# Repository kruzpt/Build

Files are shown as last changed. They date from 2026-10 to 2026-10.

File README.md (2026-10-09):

# Clínica Essencial — placa QR e NFC

Projeto de uma placa de balcão para impressão 3D e edição no Autodesk Fusion.

## Ficheiros

- **[Base Premium — download separado, encaixe original](downloads/essencial-base-premium.zip?raw=true)**
- [Base Premium — código Fusion](fusion/EssencialBasePremium/EssencialBasePremium.py)
- [Base Premium — medidas e instruções](fusion/EssencialBasePremium/README.md)
- [Base Premium — esquema das medidas](designs/essencial-base-premium-medidas.png)
- **[A1 + avaliações Google — download atual](downloads/essencial-fusion-a1-avaliacoes.zip?raw=true)**
- [A1 + avaliações Google — código Fusion](fusion/EssencialA1Reviews/EssencialA1Reviews.py)
- [A1 + avaliações Google — esquema atualizado](designs/essencial-a1-avaliacoes-esquema.png)
- [Instruções e endereços para programar NFC](fusion/EssencialA1Reviews/README.md)
- **[Bambu A1 — download (link Google ainda provisório)](downloads/essencial-fusion-a1.zip?raw=true)**
- [Bambu A1 — código Fusion](fusion/EssencialA1/EssencialA1.py)
- [Bambu A1 — esquema com dimensões completas](designs/essencial-a1-esquema.png)
- [Bambu A1 — instruções e pendência do link de avaliações](fusion/EssencialA1/README.md)
- **[V4 — download com QR de 64 mm](downloads/essencial-fusion-v4-qr64.zip?raw=true)**
- [V4 — código Fusion](fusion/EssencialV4/EssencialV4.py)
- [V4 — esquema atualizado](designs/essencial-v4-qr64-esquema.png)
- [V4 — dimensões e impressão](fusion/EssencialV4/README.md)
- **[V3 Fast — download da versão otimizada](downloads/essencial-fusion-v3-fast.zip?raw=true)**
- [V3 Fast — código e indicação de progresso](fusion/EssencialV3Fast/EssencialV3Fast.py)
- [V3 Fast — instruções](fusion/EssencialV3Fast/README.md)
- **[V3 — dois QR, símbolos e etiquetas NFC encapsuladas](fusion/EssencialV3/EssencialV3.py)**
- [Download do pacote Fusion V3](downloads/essencial-fusion-v3.zip?raw=true)
- [V3 — esquema frontal](designs/essencial-v3-esquema.png)
- [V3 — instruções de pausa e montagem](fusion/EssencialV3/README.md)
- [Placa Fusion com QR Instagram integrado](fusion/EssencialV2Instagram/EssencialV2Instagram.py)
- [Download: Fusion + STL QR + imagem](downloads/essencial-fusion-instagram.zip?raw=true)
- [STL: pastilha QR independente](downloads/instagram-qr-51mm.stl?raw=true)
- [QR Instagram — imagem](designs/instagram-qr.png)
- [Instruções de impressão e contraste do QR](fusion/README-Instagram.md)
- [Script V2 — duas peças e nova coluna](fusion/EssencialV2/EssencialV2.py)
- [Instruções e medidas do encaixe V2](fusion/EssencialV2/README.md)
- [Download do pacote Fusion V2](downloads/essencial-fusion-v2.zip?raw=true)
- [Script Python para Fusion](fusion/EssencialDraft/EssencialDraft.py)
- [Como executar no Fusion](fusion/README.md)
- [Download do pacote Fusion](downloads/essencial-fusion-draft.zip?raw=true)
- [Desenho conceptual](designs/clinica-essencial-conceito-v1.png)
- [Download do desenho em ZIP](downloads/clinica-essencial-draft.zip?raw=true)

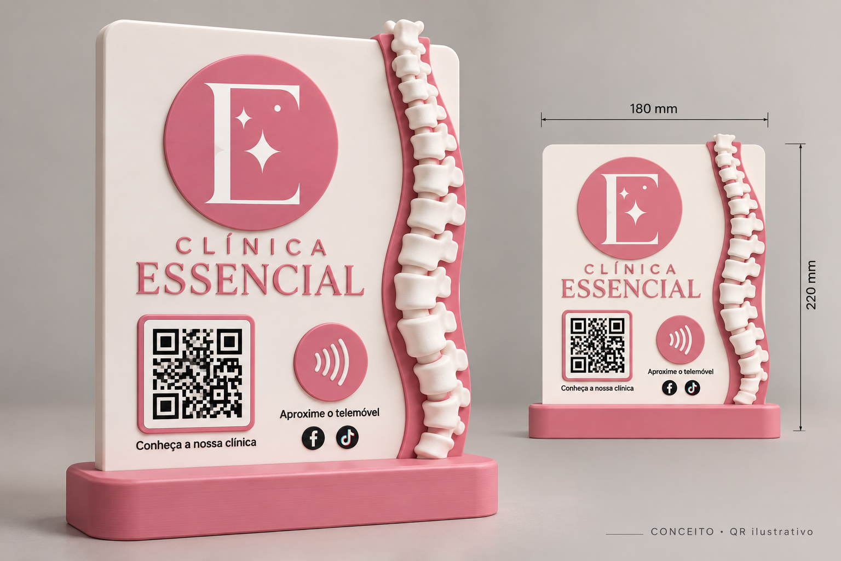
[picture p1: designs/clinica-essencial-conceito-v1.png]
Conceito inicial


O desenho conceptual mostra a primeira proposta. O script inclui uma alteração
posterior: logótipo a prolongar-se para fora do canto superior esquerdo, com a
mesma espessura da placa. Por isso, a imagem não representa exatamente o CAD.

## Estado do draft

A **Base Premium** substitui apenas a base: conserva 160 × 70 × 18 mm,
a ranhura útil 120,6 × 5,5 × 12,8 mm e a entrada alargada original.
Tem cantos R12, bordos superiores exteriores R2 e chanfro frontal de 8 mm,
sem alterar a zona de encaixe. O script é independente e cria um novo documento.

A versão atual **EssencialA1Reviews** mantém a peça completa com **208 × 242 mm**
e os QR de 64 mm. O Google abre o formulário de avaliação com o endereço que
o utilizador confirmou no navegador e no telemóvel. A matriz Google foi
regenerada com correção M para manter módulos de 1,422 mm; as cavidades NFC,
pausa Z=3,8 mm, encaixe e geração otimizada permanecem iguais. Use o mesmo
endereço de avaliações na etiqueta NFC inferior.

A versão anterior **Bambu A1** reorganiza o topo e reduz apenas o círculo do logótipo:
a placa completa, incluindo saliências e língua, fica com **208 × 242 mm**.
Com brim de 5 mm ocupa 218 × 252 mm. Mantém QR de 64 mm, etiquetas, pausa e
encaixe. **O QR Google ainda usa o link de partilha que abre pesquisa; o
endereço direto das avaliações está pendente e não foi substituído por um
endereço presumido.**

A **V4** aumenta os QR para 64 × 64 mm. A placa fica com 200 × 220 mm para
dar espaço aos símbolos, às zonas NFC e à coluna. Mantém a construção
otimizada dos QR, duas peças, as medidas da base/encaixe e a pausa após
Z=3,8 mm. Ambos os QR do esquema descodificam para os mesmos destinos.

A **V3 Fast** mantém a geometria da V3, mas gera os QR em duas extrusões
conjuntas em vez de 628 operações individuais. Inclui cálculo adiado dos
sketches e janela de progresso/cancelamento entre etapas. A igualdade dos
retângulos QR foi verificada; o tempo real no Fusion continua por confirmar.

A **V3** reorganiza a frente em duas linhas: Instagram/Google à esquerda,
respetivo QR no centro e símbolo contactless à direita. Não tem inscrições
“QR”/“NFC”. Mantém duas peças e inclui duas cavidades internas para etiquetas
NFC redondas de 25 mm, a inserir numa pausa após Z=3,8 mm. O E e as estrelas
foram redesenhados com curvas a partir da referência, sem barra central.
O logótipo é uma aproximação manual, não o vetor original. Consulte as
instruções antes de imprimir; ponte do teto, execução no Fusion e leitura
física ainda precisam de validação.

A variante **EssencialV2Instagram** inclui um QR funcional para
`https://www.instagram.com/clinicaessencial_setubal/`, em relevo e unido à
placa. O PNG e a projeção superior do STL foram descodificados para confirmar
o endereço; a impressão física e a execução da variante no Fusion continuam
pendentes. Use módulos pretos sobre fundo branco.

Placa de 180 × 220 × 5 mm, base separada, alojamento traseiro para etiqueta NFC
de 26 mm e zona reservada para QR. Na V2 sem Instagram, o QR não contém um endereço e a
etiqueta NFC tem de ser comprada e programada à parte. Letras são textos de
sketch, não sólidos para impressão. O logótipo é uma aproximação geométrica.

O utilizador confirmou que o script V1 executou no Fusion. A V2 substitui
os blocos por vértebras arredondadas com projeções curvas, tendo em conta um
bico de 0,4 mm. Cria duas peças, cada uma com um corpo sólido: placa e base.
A base tem uma ranhura de 5,5 mm para uma língua de 5 mm, com entrada alargada
e espaço no fundo. A V2 ainda precisa de execução no Fusion e teste físico
do encaixe; o draft não está validado para impressão final.

Os ficheiros entregues ficam neste repositório: scripts em `fusion/`, desenhos
em `designs/` e pacotes em `downloads/`.

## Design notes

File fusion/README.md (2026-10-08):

# Clínica Essencial — Fusion concept

1. Extract the ZIP, keeping the `EssencialDraft` folder and its Python file together.
2. Open Autodesk Fusion and switch to the Design workspace.
3. Open Utilities → Scripts and Add-Ins (or search for that command with S).
4. In Scripts, use the + / Add command to select the `EssencialDraft` folder.
5. Select EssencialDraft and Run. It creates a new document.
6. Save the result as an .f3d file.

The panel lies in XY; Z is its thickness. Use a front/top view normal to XY
to see the layout. All editable constants at the start of the script use mm.

Draft dimensions: 180 × 220 × 5 mm panel; 76 mm logo circle centered at
(28, 220), extending beyond the upper-left edge. The panel and logo silhouette
are a single body. The stylised E and sparkle are separate flush colour inlays.
The base is a separate part, shown assembled, with a 5.3 mm slot.
The NFC rear recess is 26 mm diameter with a 1 mm front wall; confirm your
physical tag size before manufacturing. No NFC electronics are supplied.

QR is a blank placeholder, not a generated code. Labels are visible sketch
text, not printable embossed lettering. Logo is an approximation, not exact
vector artwork. Vertebrae are simplified rectangular reliefs. Final fillets,
anatomical shaping, exact branding and manufacturing checks remain to be done.

Python syntax was checked in the cloud. Fusion APIs and generated geometry
cannot be executed or validated here; run this draft in Fusion before export.
If creation fails, copy the full error dialog for diagnosis.

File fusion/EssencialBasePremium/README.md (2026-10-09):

# Base Premium — substituição compatível com a placa A1

Script independente: cria **apenas a base**, num documento novo do Fusion.
Não altera a placa, os QR, o logótipo ou as cavidades NFC.

Extraia o ZIP e adicione a pasta `EssencialBasePremium` em **Utilities →
Scripts and Add-Ins → Scripts → + / Add**. Execute, guarde como `.f3d`
e exporte o componente em mm, à escala 100%.

## Desenho revisto

- Exterior **160 × 70 × 18 mm**, conservando a área de apoio.
- Cantos exteriores **R12 mm** e bordos superiores exteriores **R2 mm**.
- Chanfro frontal **8 × 8 mm a 45°**; a frente fica com 10 mm de altura.
- Topo horizontal com 18 mm de altura na zona da ranhura. Placa vertical.
- Um único sólido. Rosa da marca como cor de apresentação, quando disponível.

O raio superior é aplicado antes de cortar o chanfro e a ranhura. Assim,
o arredondamento não altera o encaixe. O chanfro é cortado de forma explícita,
sem depender da seleção automática de arestas tangentes. As arestas de
transição do chanfro não recebem um fillet adicional.

O desenho segue a imagem conceptual, mas as medidas e a geometria deste
script são a referência de fabricação; a imagem não é um render CAD.

## Encaixe preservado de EssencialA1Reviews

| Elemento | Medida |
| --- | --- |
| Língua existente da placa | 120 × 5 × 12 mm |
| Ranhura útil | **120,6 × 5,5 mm** |
| Profundidade total da ranhura | **12,8 mm** |
| Folga na espessura | 0,25 mm por lado |
| Folga nas extremidades | 0,30 mm por lado |
| Folga no fundo | 0,80 mm |
| Entrada alargada | 121,6 × 6,5 mm, profundidade 1 mm |
| Material sólido por baixo | 5,2 mm |

A ranhura permanece centrada. Coordenadas locais: X=19,7…140,3 mm,
Y=32,25…37,75 mm, piso Z=5,2 mm. A entrada alargada começa em Z=17 mm;
é a mesma entrada em degrau da base anterior, não um novo encaixe inclinado.

Imprima **fundo plano na mesa e ranhura para cima**, em placa separada.
Não precisa de pausa NFC. Não escale a peça para ajustar o encaixe.
Teste com a língua impressa: a folga geométrica não elimina a variação
de impressão, material ou calibração.

## Validação e limites

Os testes comparam as medidas com o script existente, verificam o afastamento
do chanfro e arredondamentos à ranhura, e exercitam o corte da ranhura com
uma API simulada.
O script verifica no próprio Fusion o sólido, o envelope exterior e as
dimensões da face do fundo da ranhura, falhando com indicação da etapa se
não corresponderem. Não requer bibliotecas externas no Fusion.

A execução com o kernel real do Fusion e o encaixe físico ainda precisam
de confirmação. Os parâmetros estão no início do código; altere-os e execute
de novo para regenerar. As features na timeline usam medidas fixas.

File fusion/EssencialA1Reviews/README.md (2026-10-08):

# Clínica Essencial — Bambu A1 com avaliações Google

Esta é a versão atual para a **Bambu A1**, com o endereço de avaliação
que o utilizador confirmou no navegador e no telemóvel. Mantém o tamanho
reduzido da A1; substitui o QR Google que antes abria a pesquisa.

## Executar

Extraia `essencial-fusion-a1-avaliacoes.zip`. Adicione a pasta
`EssencialA1Reviews` em **Utilities → Scripts and Add-Ins → Scripts → + / Add**
no Fusion e execute. Cria um documento novo. Guarde como `.f3d` e exporte cada
componente separadamente, em mm. Imprima placa e base em placas separadas.

## Dimensões mantidas

| Elemento | Dimensão |
| --- | --- |
| Placa completa, incluindo círculo e língua | **208 × 242 mm** |
| Envelope com brim de 5 mm por lado | 218 × 252 mm |
| Painel retangular | 200 × 198 × 5 mm |
| Base separada | 160 × 70 × 18 mm |
| Ambos os campos QR, incluindo margem branca | **64 × 64 mm** |

Use escala 100% no Bambu Studio, face traseira da placa na mesa, centrada.
Confirme a disposição no perfil da A1 e as zonas reservadas pelo slicer.
Não reduza o modelo globalmente: as etiquetas, o encaixe e os QR mantêm
dimensões de fabricação.

## QR e NFC — endereços definitivos deste draft

- **Superior / Instagram:** https://www.instagram.com/clinicaessencial_setubal/
- **Inferior / Google:** https://search.google.com/local/writereview?placeid=ChIJvVHxDlBCGQ0Rcw8jp4G4TNg

Grave esses mesmos endereços nas etiquetas NFC superior e inferior antes
de as inserir. O script produz os símbolos e cavidades, não programa etiquetas.
O formulário Google pode pedir login; se a pessoa já avaliou, pode mostrar
a avaliação existente para editar, como aconteceu no teste do utilizador.

O novo Google QR usa correção **M** para manter módulos maiores com este URL
mais comprido. A matriz tem 45 × 45 módulos incluindo margem de quatro módulos
por lado: passo 1,422 mm, traço preto mínimo cerca de 1,402 mm. Instagram
mantém correção Q e o mesmo passo. Não há símbolos/logótipos dentro dos QR.

Use módulos pretos, fundo e margem brancos, acabamento mate e bico de 0,4 mm.
Relevo dos QR: 0,6 mm. Teste a leitura da impressão física antes de entregar.
O JPG incluído tem a mesma matriz do novo Google QR impresso.

## Montagem e pausa NFC

Continuam a existir **duas peças**, um corpo sólido por componente. O encaixe
mantém língua 120 × 5 × 12 mm e ranhura 120,6 × 5,5 mm, com entrada alargada e
folga no fundo. Confirme o encaixe numa amostra.

Etiquetas Ø25 mm: cavidades Ø25,8 mm, com piso em Z=3,0 mm e teto a começar
em Z=3,8 mm. **Pause após terminar Z=3,8 mm, antes da primeira camada do teto.**
Com todas as camadas a 0,2 mm, incluindo a primeira, pause após a camada 19,
antes da 20. Confirme na pré-visualização e não gere suportes nas cavidades.
Cole as etiquetas planas no piso e retome para fechar. O draft reserva 0,8 mm
de altura; confirme a espessura da etiqueta/adesivo e teste o bridging do teto.

O logótipo curvo, coluna, símbolos e disposição são preservados da versão A1.
A criação permanece otimizada, com dois sketches e duas extrusões para os QR,
janela de progresso e cancelamento entre etapas.

## Validação

O utilizador confirmou o destino do link e a leitura do JPG anterior de teste no
telemóvel. Na cloud, a nova matriz Google, o JPG correspondente e os dois QR
do esquema foram descodificados para os endereços acima. Envelope, folgas,
pausa e geometria são verificados por testes; o ZIP corresponde ao script.

A execução desta variante no Fusion, fatiamento A1 e impressão física ainda
precisam de confirmação. O esquema é um desenho de disposição, não render CAD.

Regenerar: `python fusion/tools/generate_a1_reviews.py` com o venv QR.

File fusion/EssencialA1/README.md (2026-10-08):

# Clínica Essencial — Bambu A1

Esta versão resolve o tamanho da peça completa, mantendo os QR de 64 mm.
**O QR Google ainda aponta para o antigo link de partilha/pesquisa. O endereço
direto das avaliações está pendente; esta versão não resolve esse destino.**

## Executar e exportar

Extraia `essencial-fusion-a1.zip` e execute a pasta `EssencialA1` em
**Utilities → Scripts and Add-Ins → Scripts → + / Add** no Fusion.
Cria um documento novo com dois componentes, um corpo por componente.

Exporte **cada componente separadamente** em milímetros. Imprima placa e
base em placas de impressão separadas; o conjunto mostrado lado a lado
no Fusion não cabe inteiro na A1 numa única disposição.

## Dimensões reais, incluindo saliências

| Elemento | Dimensão XY |
| --- | --- |
| Painel retangular | 200 × 198 mm |
| Placa completa, com logótipo e língua | **208 × 242 mm** |
| Envelope da placa com brim de 5 mm em cada lado | **218 × 252 mm** |
| Área nominal Bambu A1 | 256 × 256 mm |
| Base separada | 160 × 70 mm |

A redução é uma reorganização do topo, não uma escala global: mantém o tamanho
dos módulos QR, a espessura da placa, as cavidades NFC e as folgas de encaixe.
O logótipo passa a 64 mm de diâmetro, com metade acima do painel. O nome da
clínica fica à sua direita; a coluna mantém a forma e foi movida 8 mm para baixo.

No Bambu Studio, coloque a face traseira da placa na mesa, à escala 100%,
e centre-a. Use brim de até 5 mm como ponto de partida, confirmando o envelope
e eventuais zonas reservadas pelo perfil antes de imprimir. Não reduza a escala
para caber: isso reduz os QR e a folga para as etiquetas de 25 mm.

## QR, etiquetas e encaixe

Mantém dois QR de 64 × 64 mm, margens brancas, símbolos sociais e contactless.
As zonas NFC e os QR mantêm as posições da V4. Cavidades Ø25,8 mm para etiquetas
Ø25 mm, de Z=3,0 a Z=3,8 mm. Pausa após terminar Z=3,8 mm, antes do teto.
Com camadas constantes de 0,2 mm, incluindo a primeira, pause após a 19.ª
camada e antes da 20.ª; confirme esse ponto na pré-visualização do slicer.

O encaixe da base mantém língua 120 × 5 × 12 mm, ranhura 120,6 × 5,5 mm,
entrada alargada e espaço no fundo. Confirme o encaixe e o bridging sobre
as etiquetas numa amostra; instruções completas em `fusion/EssencialV3/README.md`.

## Google: o que falta

O link de partilha abre Google Search, onde podem aparecer anúncios. Para
abrir diretamente o formulário de avaliação, obtenha **Pedir avaliações** na
gestão do Perfil da Empresa, normalmente um link `g.page/r/.../review` ou
`search.google.com/local/writereview?placeid=...`. Não se pode substituir
`placeid` pelo `kgmid` `/g/11f4pqv2c4`: são identificadores diferentes.

Para quem não tem acesso à gestão, um link da ficha aberta no **Google Maps**
pode fornecer um Place ID/CID para investigação. Não basta o nome pesquisado.
Na cloud, a consulta ao Google foi bloqueada pelo proxy com HTTP 403, por isso
não foi possível obter ou verificar o identificador correto daqui.

## Validação

Envelope completo e espaço para brim calculados; geometria/QR/folgas e pausa
verificados por testes na cloud. Os QR do esquema descodificam para os destinos
atuais (Google ainda provisório). Execução no Fusion, fatiamento no perfil da
A1 e impressão física continuam por validar.

Regenerar: `python fusion/tools/generate_essencial_a1.py` com o venv QR.

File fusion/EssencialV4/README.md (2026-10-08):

# Clínica Essencial V4 — QR de 64 mm

Extraia `essencial-fusion-v4-qr64.zip`, adicione a pasta `EssencialV4` em
**Utilities → Scripts and Add-Ins → Scripts → + / Add** no Fusion e execute.
Cria um documento novo, com progresso e cancelamento entre etapas.

## Alterações

- Ambos os campos QR passaram de **52 para 64 × 64 mm**, incluindo a margem
  branca de quatro módulos por lado.
- A placa passou de **180 para 200 mm de largura**, mantendo 220 mm de altura
  e 5 mm de espessura. Isto permite aumentar os QR sem invadir as zonas NFC.
- Instagram em cima e Google em baixo, símbolos à esquerda e contactless
  à direita. Os campos são x=49..113 mm, y=81..145 e y=4..68 mm.
- As duas etiquetas têm centros (133,113) e (133,36) mm. A coluna foi movida
  20 mm para a direita; o texto da clínica foi ajustado para dar espaço.
- O logótipo mantém a posição e os contornos da V3.

| Código | Matriz incluindo margem | Passo de cada módulo |
| --- | --- | --- |
| Instagram | 45 × 45 | 1,422 mm |
| Google | 41 × 41 | 1,561 mm |

Os retângulos em relevo têm um recuo técnico de 0,01 mm nas bordas; o traço
mínimo preto resultante é cerca de 1,402 mm no Instagram e 1,541 mm no Google.
O relevo continua com 0,6 mm. Módulos pretos sobre branco, superfície mate e
margens brancas limpas são necessários para uma boa leitura. Bico de 0,4 mm
e camada de 0,2 mm são pontos de partida; teste uma amostra antes da placa.

## Mantido da V3 Fast

- Duas peças, com um corpo sólido por componente: placa e base.
- **Apenas dois sketches e duas extrusões para os QR**, independentemente
  do aumento de tamanho; não se aumentou o número de operações de QR.
- Base de 160 × 70 × 18 mm e língua 120 × 5 × 12 mm. O encaixe mantém
  ranhura 120,6 × 5,5 mm, entrada alargada e espaço de 0,8 mm no fundo.
- Etiquetas NFC de Ø25 mm, cavidades Ø25,8 mm, entre Z=3,0 e Z=3,8 mm.
- Piso e teto das cavidades fechados no CAD, sem tampas adicionais.

**Pausa após terminar Z=3,8 mm, antes da primeira camada do teto.** Com todas
as camadas de 0,2 mm, incluindo a primeira, pause depois da camada 19 e antes
da 20. Confirme na pré-visualização do slicer. Programe a etiqueta superior
para Instagram e a inferior para Google, teste e cole-as no piso das cavidades.

Imprima a placa deitada, face decorada para cima. Não gere suportes dentro
das cavidades. Confirme espessura da etiqueta (até cerca de 0,6 mm neste draft),
temperatura admissível e bridging do teto numa amostra. Consulte também as
instruções detalhadas em `fusion/EssencialV3/README.md` no GitHub.

A silhueta total da placa, com círculo e língua, ocupa cerca de **210 × 270 mm**
em XY; verifique a área útil da impressora antes de fatiar.

## Validação

QR descodificados para os mesmos endereços no esquema publicado; contornos,
folgas, separação das zonas e altura de pausa verificados na cloud. A rotina
de QR é testada com API simulada para confirmar duas extrusões e as novas
dimensões dos módulos. A execução real no Fusion e a impressão continuam
pendentes. O PNG é um esquema, não um render CAD.

Regenerar com as dependências QR: `python fusion/tools/generate_essencial_v4.py`.

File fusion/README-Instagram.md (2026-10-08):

# QR 3D — Instagram Clínica Essencial

Destino exato: https://www.instagram.com/clinicaessencial_setubal/

## Placa com QR integrado — continua a ter duas peças

No Fusion, adicione a pasta `EssencialV2Instagram` em **Utilities → Scripts
and Add-Ins → Scripts → + / Add** e execute. Cria um documento novo com a
placa V2 e base. O QR substitui o alojamento vazio por módulos em relevo,
unidos ao mesmo corpo da placa; a base continua a ser a segunda peça.

Este script contém a correção do arco da coluna. A geometria do QR é criada
em filas de retângulos; a geração pode demorar mais do que a V2.

Campo QR: 52 × 52 mm, incluindo margem branca de quatro módulos em cada
lado. Módulos: cerca de 1,156 mm, relevo de 0,6 mm. O QR ocupa x=17..69,
y=30..82 na placa. Não pinte nem decore a margem branca.
Os retângulos têm um recuo de 0,01 mm nas bordas para evitar contactos
geométricos degenerados; o padrão foi verificado após essa alteração.

## STL alternativo — pastilha independente

`instagram-qr-51mm.stl` é uma pastilha de 51,2 × 51,2 mm, cantos arredondados,
base de 0,6 mm e relevo preto de 0,6 mm (total 1,2 mm). Cabe no alojamento
de 52 mm da V2 anterior com 0,4 mm livres por lado, para colagem. Esta opção
acrescenta uma peça; não é necessária se usar o script com QR integrado.

Importe o STL no slicer em **mm**, sem redimensionar os eixos separadamente.
Use fundo branco e módulos pretos. Com camadas de 0,2 mm, imprima as primeiras
3 camadas em branco e mude para preto na primeira camada acima de z=0,6 mm.
Confirme a mudança na pré-visualização do slicer. O STL não contém cores.
A pastilha foi construída como um corpo fechado, unido, sem ilhas soltas.

## Impressão e contraste

O tamanho foi escolhido para bico de 0,4 mm: cada módulo tem cerca de 1,14 mm
na pastilha. Use camadas de 0,2 mm como ponto de partida e superfície mate.
Relevo numa única cor não assegura contraste suficiente para leitura.

Na placa integrada, QR, letras e marcador NFC estão na mesma altura de
relevo; uma mudança para preto nessa altura também colore esses elementos
e as camadas superiores da coluna. Para cores independentes, use pintura
cuidadosa ou atribuição de cores por regiões num slicer multimaterial.
Não passe tinta entre os módulos do QR.

## Verificações e limites

- PNG descodificado por OpenCV: endereço exato confirmado.
- Projeção superior reconstruída a partir do STL exportado: endereço exato
  confirmado, e cada módulo comparado com a matriz QR.
- STL fechado, orientação das faces consistente e um único sólido.
- Script Fusion: sintaxe verificada; execução desta variante ainda pendente.
- Leitura da impressão física: ainda pendente. Teste com o telemóvel antes
  de colar/entregar. A leitura depende do contraste e qualidade da impressão.

O QR abre o endereço diretamente; não depende de um serviço de QR dinâmico.
A geração/validação do código não confirma a disponibilidade do perfil no
Instagram. Para NFC, grave o mesmo endereço na sua etiqueta.

Regenerar os ficheiros: instale `fusion/tools/requirements-qr.txt` num venv
e execute `python fusion/tools/generate_instagram_qr.py`.

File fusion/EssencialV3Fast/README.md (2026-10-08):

# Clínica Essencial V3 Fast

A V3 original criava **628 sketches e 628 extrusões só para os QR**
(352 Instagram + 276 Google). Esta versão cria **dois sketches e duas
extrusões**, preservando todos os retângulos, dimensões e endereços.

Os sketches são resolvidos depois de desenhar os contornos e permanecem
ocultos. Os QR são unidos à placa no fim, para que os restantes cortes e
decorações trabalhem sobre uma peça mais simples. Há uma janela de progresso
com cancelamento entre etapas e atualização da interface.

## Executar

Não execute duas instâncias ao mesmo tempo. Se a V3 antiga ainda estiver
a executar, espere que termine ou cancele quando a aplicação permitir.
Se for necessário reiniciar o Fusion, tenha atenção a outros documentos
com alterações por guardar.

Extraia `essencial-fusion-v3-fast.zip`, adicione a pasta `EssencialV3Fast`
em **Utilities → Scripts and Add-Ins → Scripts → + / Add** e execute.
Cria um documento novo. Quando terminar, guarde como `.f3d`.

O progresso pode ficar parado enquanto uma operação geométrica está a ser
calculada: não é uma medição contínua nem há cancelamento dentro do cálculo
do kernel. Se surgir erro, a mensagem indica a etapa e o traceback.

## Modelo preservado

- Duas peças: placa e base, um corpo sólido em cada componente.
- Símbolos Instagram e Google, QR respetivos e ondas contactless.
- Logótipo com serifas curvas, estrelas e sem barra central.
- Duas cavidades internas de Ø25,8 mm para etiquetas de Ø25 mm.
- Pausa após Z=3,8 mm, antes do teto, com a placa deitada, face para cima.
- Mesmas folgas de encaixe da V3 e relevo dos QR de 0,6 mm.

As instruções completas de impressão/cores/etiquetas estão em
`fusion/EssencialV3/README.md` no repositório. Confirme a espessura da etiqueta,
a pausa no slicer e o bridging do teto numa amostra antes da placa completa.

## Validação

Os retângulos emitidos pela rotina de QR foram comparados com os da V3,
e testes com uma API simulada verificam que há uma única extrusão por QR.
Os testes de geometria da V3 também são aplicados ao código otimizado.
O ZIP corresponde ao script atual.

Não foi possível executar Autodesk Fusion na cloud: a redução de operações
foi verificada, mas o tempo real e a conclusão no Fusion precisam de ser
confirmados na máquina do utilizador.

Regenerar: `python fusion/tools/optimize_essencial_v3.py`.

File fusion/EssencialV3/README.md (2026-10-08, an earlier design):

# Clínica Essencial V3 — Instagram, Google e NFC encapsulado

## Executar no Fusion

Descarregue `essencial-fusion-v3.zip`, extraia e adicione a pasta `EssencialV3`
em **Utilities → Scripts and Add-Ins → Scripts → + / Add**. Execute o script
e guarde o documento novo como `.f3d`. Não altera documentos já abertos.

Continuam a existir duas peças: placa com os detalhes unidos e base separada.
As peças são mostradas deitadas lado a lado, prontas para inspeção/exportação.
O script confirma que cada componente tem apenas um corpo sólido.

## Frente

- Linha superior: símbolo Instagram → QR Instagram → ondas contactless.
- Linha inferior: símbolo Google → QR Google → ondas contactless.
- Não existem inscrições “QR” ou “NFC”. Mantém-se o nome da clínica.
- Cada campo QR inclui uma margem branca de quatro módulos, dentro dos 52 mm.
- Logo no canto superior esquerdo, com a silhueta coplanar com a placa.
- Coluna vertebral em relevo, preservada da V2 corrigida.

Destinos:

- Instagram: https://www.instagram.com/clinicaessencial_setubal/
- Google: https://share.google/2xgo7t8ZFrO7ukORw

O QR Google abre a ficha partilhada, não o formulário de nova avaliação.
As ondas contactless são símbolos; as etiquetas eletrónicas são compradas
à parte e devem ser programadas, uma com cada endereço, antes de inserir.

## Etiquetas NFC internas — pausa na impressão

Imprima a placa **deitada, face decorada para cima, fundo em Z=0**. Há uma
cavidade sob cada símbolo contactless, centros (121,112) e (121,47) mm.

| Medida | Valor |
| --- | --- |
| Etiqueta informada pelo utilizador | circular, Ø25 mm, autocolante fino |
| Cavidade | Ø25,8 mm (0,4 mm livres por lado) |
| Piso da cavidade | Z=3,0 mm |
| Altura livre | 0,8 mm |
| Início do teto | Z=3,8 mm |
| Plástico acima da cavidade | 1,2 mm, até Z=5,0 mm |

1. Programe e teste as duas etiquetas; confirme a espessura real (incluindo
   adesivo). Para este draft, use etiquetas com espessura até cerca de 0,6 mm,
   deixando espaço até ao teto. Altere os valores no script se for necessário.
2. No slicer, configure a pausa **depois de terminar Z=3,8 mm e antes de
   começar a primeira camada do teto**. Com TODAS as camadas de 0,2 mm, inclui
   a primeira, isso significa após a camada 19, antes da camada 20. Se o slicer
   coloca a pausa antes da camada selecionada, selecione a camada 20. Confirme
   o resultado na pré-visualização, não apenas pelo número apresentado.
3. Não gere suportes/infill dentro das duas cavidades. Na pausa, o piso e as
   paredes já devem existir e os dois círculos estar abertos na face superior.
4. Cole cada etiqueta no piso da respetiva cavidade. Deve ficar plana, abaixo
   de Z=3,8 mm, sem invadir o percurso do bico. A etiqueta superior é Instagram;
   a inferior é Google. Retome a impressão para fechar as cavidades.
5. Teste a leitura no telemóvel através da face final.

O teto exige uma ponte de cerca de 26 mm. Inspecione bridging no slicer e
faça uma pequena amostra desta região antes de imprimir a placa inteira.
Não se assume que o teto fica bem impresso sem esse teste. Verifique também
a temperatura de serviço da etiqueta junto do fornecedor antes de encapsular.

As cavidades estão completamente fechadas no CAD final: não há tampas extras
nem acesso pela face traseira depois de imprimir.

## Logo e cores

O E foi redesenhado manualmente a partir da imagem: serifas e curvas
assimétricas, sem barra central, duas estrelas de lados curvos e o ponto.
Está gravado 0,6 mm na face do círculo, preservando um único corpo da placa.
É uma aproximação da referência raster, não o ficheiro vetorial original.

Pinte o círculo rosa e o E/estrelas/ponto brancos para reproduzir a marca.
Os símbolos sociais são monocromáticos. Mantenha os módulos QR pretos e as
áreas em volta brancas. Não coloque tinta ou decorações nas margens do QR.
Uma troca de cor por camada pode colorir vários detalhes ao mesmo tempo;
use pintura ou seleção por região para cores independentes.

## Base e impressão

O encaixe da V2 é preservado: língua 120 × 5 × 12 mm, ranhura 120,6 × 5,5 mm,
profundidade 12,8 mm, entrada alargada e 0,8 mm de espaço no fundo. Ajuste a
folga depois de uma amostra. Bico de 0,4 mm; QR de 52 mm com módulos superiores
a 1 mm e relevo de 0,6 mm, ondas contactless com traço de 1,4 mm.

O conjunto da placa ocupa aproximadamente 190 × 270 mm; confirme que cabe
na mesa, rodando no plano XY se necessário, sem mudar o Z de pausa.

## Validação e ficheiros

O PNG `essencial-v3-esquema.png` é um esquema, não um render CAD. As curvas
laterais da coluna são simplificadas; o script mantém as vértebras da V2.
Os QR do esquema foram descodificados para os endereços acima.

A sintaxe, os contornos, a separação dos elementos e o espaço das cavidades
são verificados na cloud. A V3 não foi executada no Fusion; impressão, ponte
do teto, encaixe e leitura física NFC/QR continuam por validar. Se a extrusão
de texto não funcionar com as fontes instaladas, o nome permanece em sketch
e o script avisa. Outros erros aparecem com traceback completo.

Regenerar: `python fusion/tools/generate_essencial_v3.py` com as dependências
de `fusion/tools/requirements-qr.txt`. O script Fusion entregue não precisa
dessas dependências: as matrizes QR e os contornos estão incluídos no `.py`.

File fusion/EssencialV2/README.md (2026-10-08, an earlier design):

# Clínica Essencial V2 — duas peças

Esta versão preserva o draft anterior e cria um documento novo no Fusion.

## Executar

1. Descarregue e extraia `essencial-fusion-v2.zip`.
2. No Fusion, abra **Utilities → Scripts and Add-Ins → Scripts**.
3. Use **+ / Add** para selecionar a pasta `EssencialV2` e execute o script.
4. Guarde o documento como `.f3d`. Exporte cada componente separadamente para
   STL ou 3MF, confirmando as unidades em milímetros.

Há dois componentes, cada um com exatamente um corpo sólido:

- **01 - Plate and spine**: placa, logótipo e relevo unidos, com língua inferior.
- **02 - Slotted base**: base com ranhura aberta por cima, mostrada ao lado.

As peças aparecem separadas para inspeção. A placa está deitada em XY; a base
também está em XY, com a ranhura para cima. Na montagem, a placa fica vertical
e a língua entra na base até os ombros da placa assentarem na face superior.

## Encaixe

| Dimensão | Valor inicial |
| --- | --- |
| Placa | 180 × 220 × 5 mm, sem contar logótipo/língua |
| Língua | 120 mm de largura × 5 mm de espessura × 12 mm de inserção |
| Base | 160 × 70 × 18 mm |
| Ranhura útil | 120,6 × 5,5 mm |
| Profundidade da ranhura | 12,8 mm |
| Folga na espessura | 0,25 mm em cada lado |
| Folga nas extremidades | 0,30 mm em cada lado |
| Espaço abaixo da língua | 0,8 mm |
| Fundo sólido da base | 5,2 mm |
| Entrada alargada | 121,6 × 6,5 mm nos primeiros 1 mm |

A entrada é um pequeno degrau alargado, não um chanfro. A folga é um ponto de
partida para FDM; a calibração, o material e o pé de elefante podem alterar
o encaixe. Faça uma amostra curta da língua/ranhura no slicer antes de imprimir
as peças inteiras. Evite compensações que eliminem a folga.

Para ajustar, altere `FIT_CLEARANCE_PER_SIDE` e os restantes valores no topo
do `.py` e execute novamente. Os parâmetros gravados no documento servem como
referência; não conduzem todas as dimensões da geometria automaticamente.

## Coluna e impressão com bico de 0,4 mm

A coluna é um relevo lateral estilizado: 7 vértebras cervicais, 12 torácicas
e 5 lombares, mais sacro/cóccix simplificados. Corpos arredondados, projeções
curvas com raiz de pelo menos 2 mm, variação de tamanho e alinhamento suave
substituem os blocos da V1. O espaço nominal entre os corpos é 1 mm e o relevo
é 2,4 mm. Não é um modelo anatomicamente rigoroso.

Os detalhes estão unidos à placa. A placa/logótipo têm 5 mm de espessura;
as letras e o marcador NFC sobressaem 0,6 mm. O logótipo é agora gravado para
evitar corpos de inlay separados. A forma do E continua aproximada.

A placa pode ser impressa deitada; a cavidade NFC na face traseira exige
analisar bridging/suportes no slicer. A base imprime com a ranhura para cima.
Uma cor por peça é suficiente; pintura ou mudança de cor por camada são
opcionais. Verifique a área da mesa: o conjunto placa/logótipo/língua ocupa
cerca de 190 × 270 mm em XY e pode precisar de rotação para caber.

O QR é um alojamento para etiqueta de 52 × 52 mm, não um código funcional.
O alojamento NFC traseiro tem 26 mm de diâmetro; confirme a medida da etiqueta
e a forma de fixação antes de imprimir. A etiqueta eletrónica não é impressa.

## Validação

Correção V2.1: o arco inferior das projeções usava três pontos alinhados,
o que produzia `RuntimeError: 3 : Some input argument is invalid` no Fusion.
O ponto intermédio foi deslocado para permitir um arco válido. Volte a
descarregar o ZIP e substitua o script local pela versão corrigida.

A sintaxe Python, a disposição das 24 vértebras e as dimensões de encaixe
foram verificadas na cloud. O script verifica no Fusion que cada componente
termina com um corpo sólido. Esta V2 ainda precisa de ser executada no Fusion
e de ter o encaixe confirmado numa impressão de teste.

Checks de regressão: `python -m unittest discover -s fusion/tests -v`.
Verificam os arcos não degenerados, as ligações entre arcos, a posição das
vértebras e as folgas de encaixe, sem substituir a execução no Fusion.

Se a extrusão de texto não for suportada pela versão/fontes do Fusion, o texto
fica como sketch e surge um aviso; nesse caso não será impresso. Outras falhas
de geometria produzem uma mensagem de erro completa.

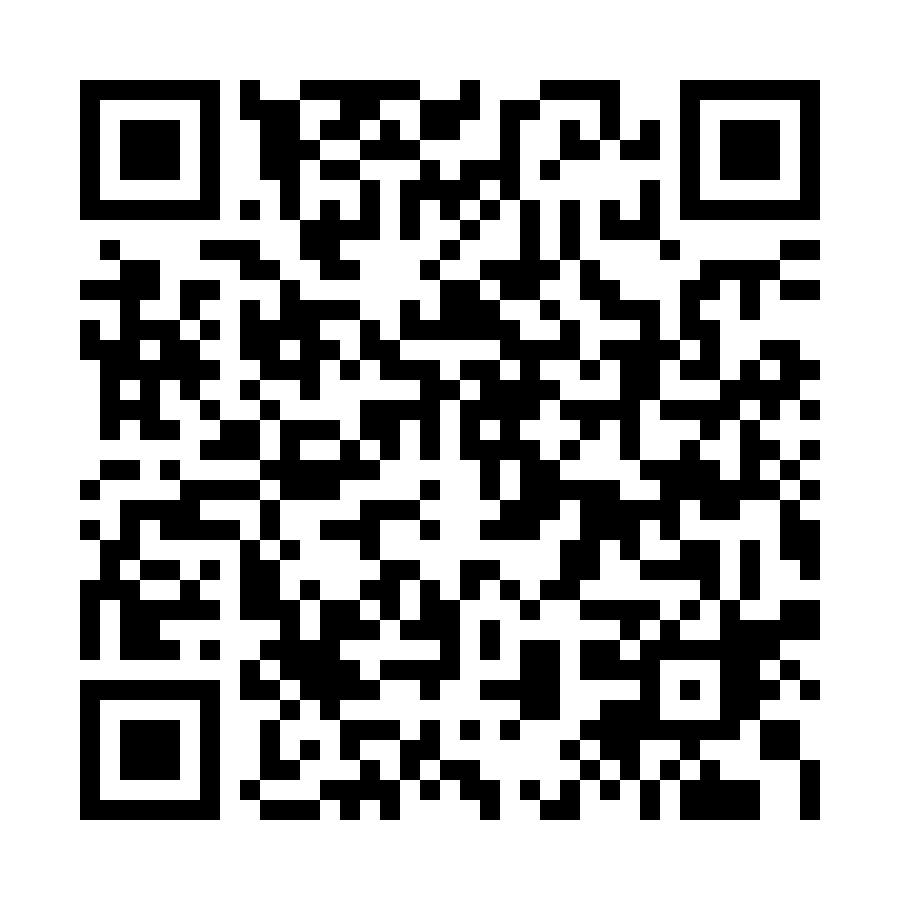
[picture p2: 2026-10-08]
designs/instagram-qr.png

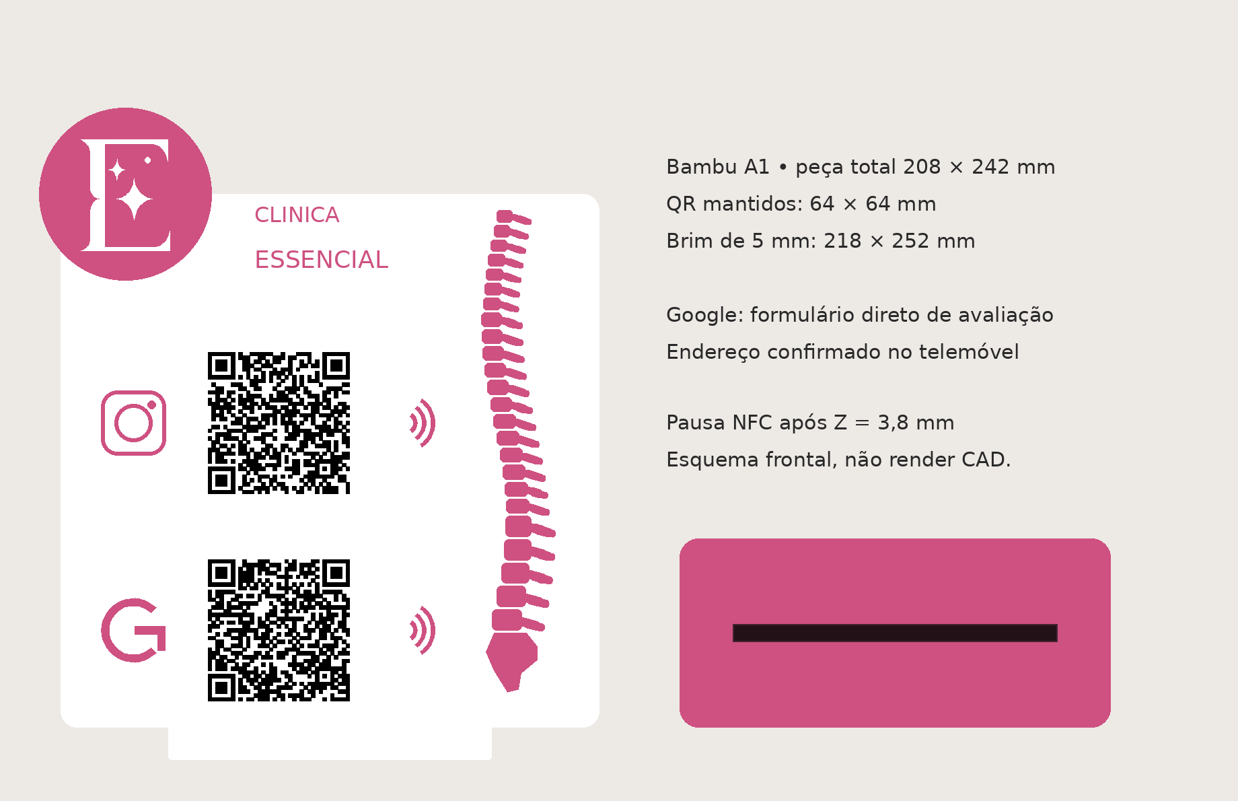
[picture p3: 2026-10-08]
designs/essencial-a1-avaliacoes-esquema.png

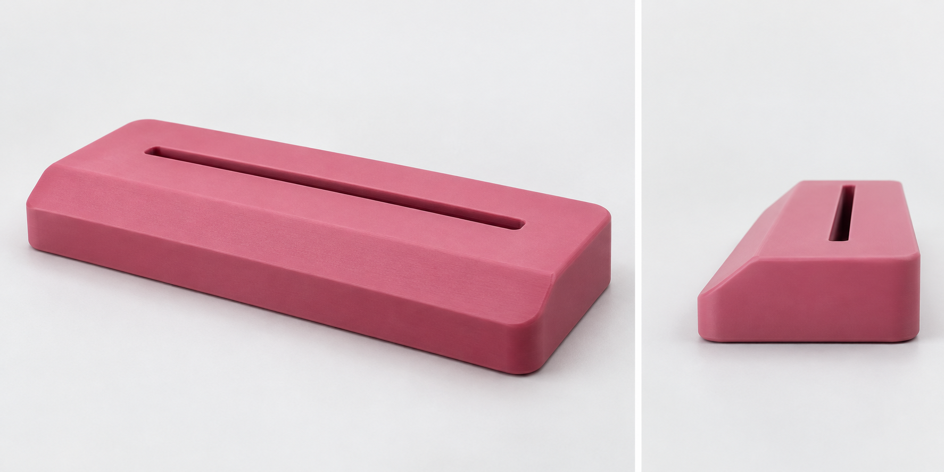
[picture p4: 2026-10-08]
designs/essencial-base-chanfrada-conceito.png

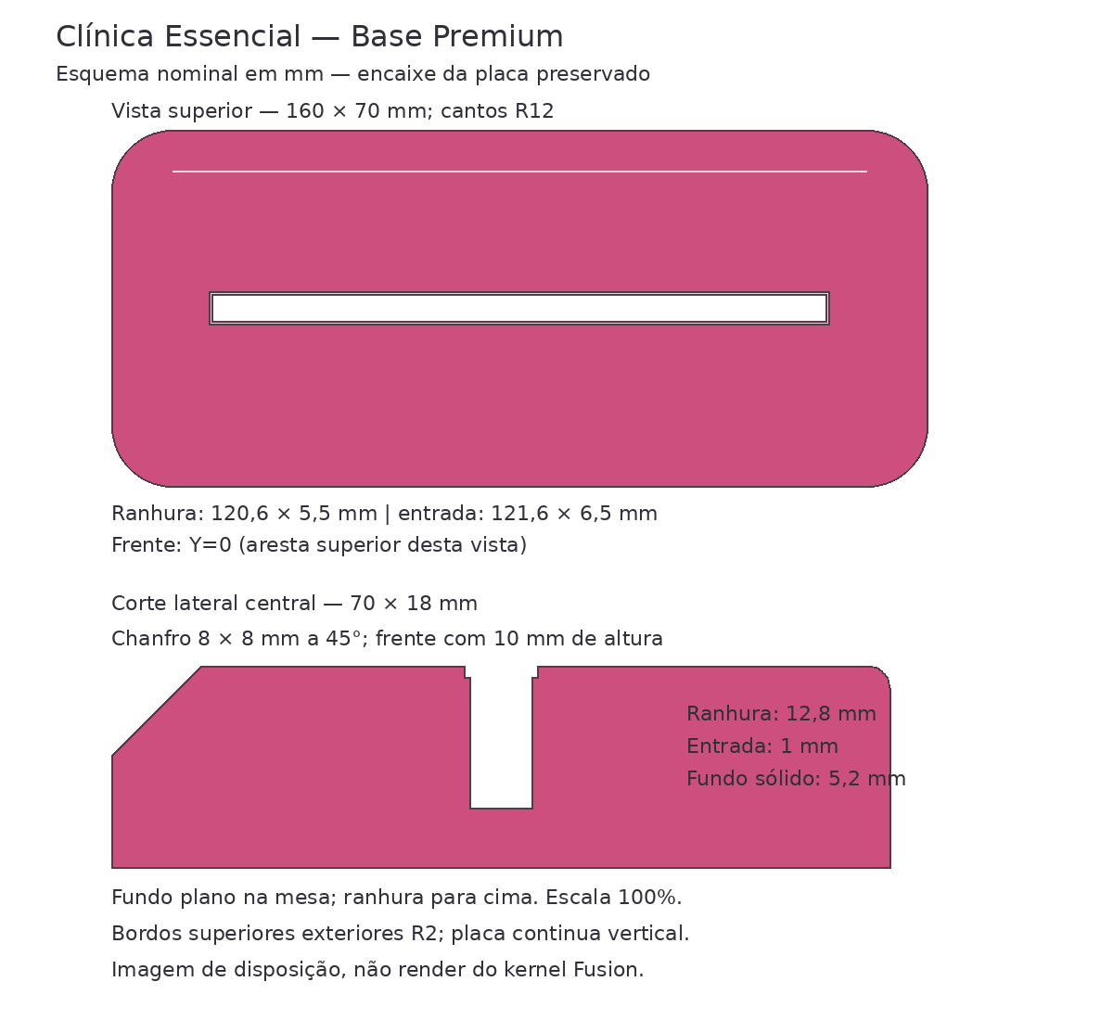
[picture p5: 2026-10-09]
designs/essencial-base-premium-medidas.png

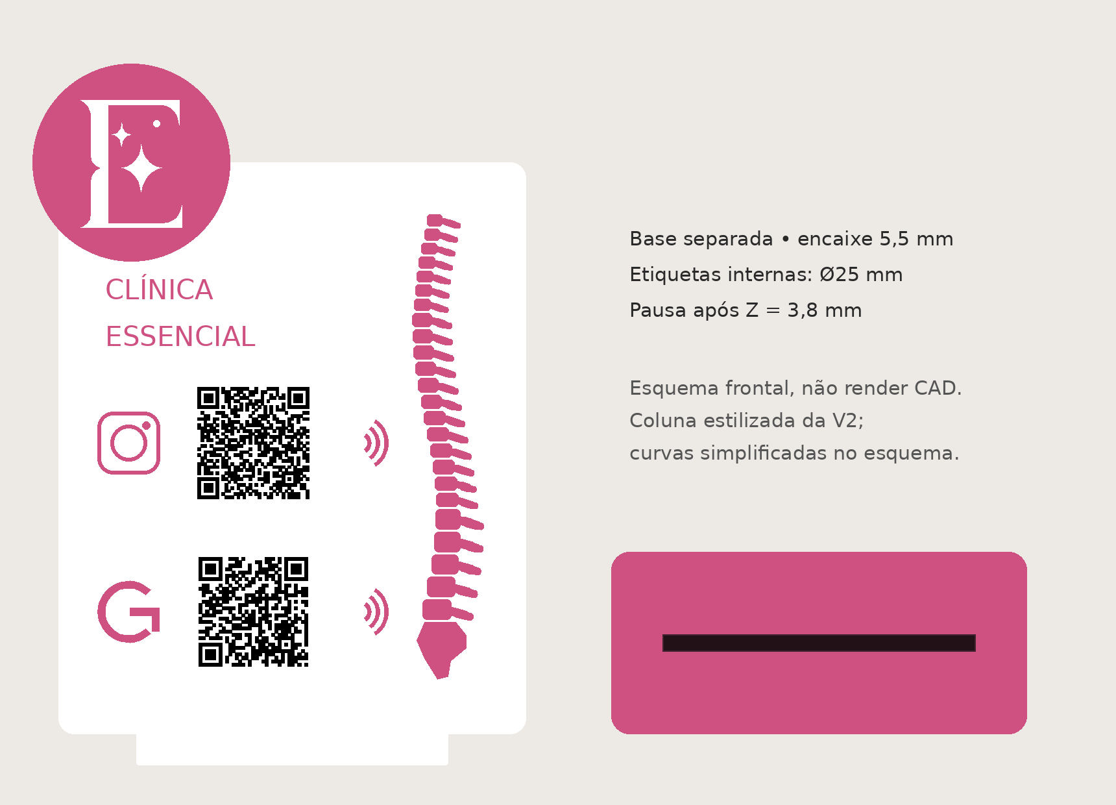
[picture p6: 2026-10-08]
designs/essencial-v3-esquema.png

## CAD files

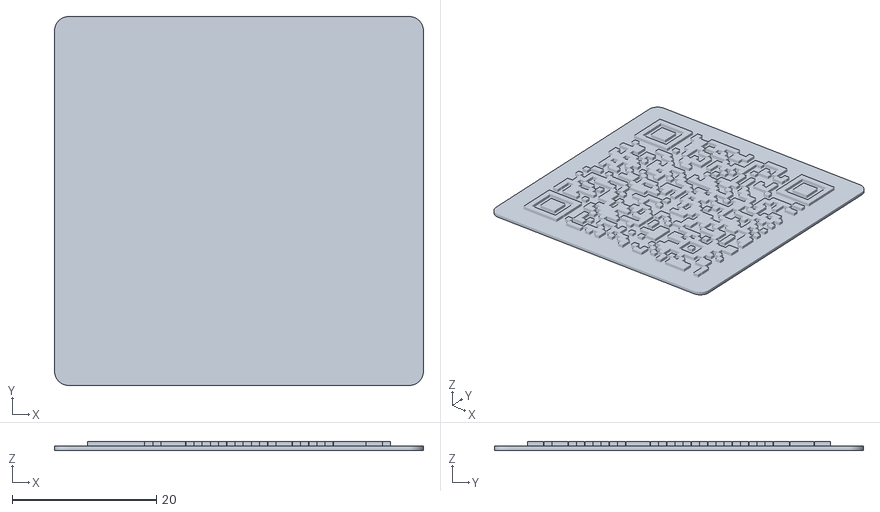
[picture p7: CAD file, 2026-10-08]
downloads/instagram-qr-51mm.stl
51.2 x 51.2 x 1.20

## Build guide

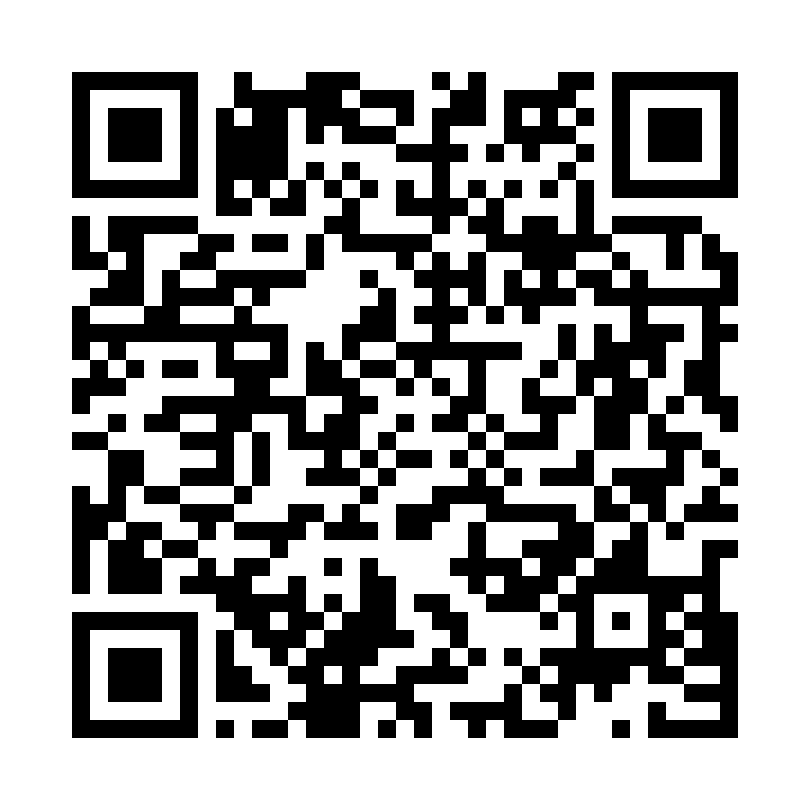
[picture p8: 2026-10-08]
designs/google-reviews-qr-print.jpg

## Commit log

2026-10-08 Add verified Instagram QR STL and integrated Fusion plaque variant
    [instagram-qr-51mm.stl]
2026-10-08 Optimize V3 QR construction with batched extrusions and progress UI
2026-10-08 Increase both QR fields to 64 mm and rebalance plaque layout
2026-10-08 Fit plaque to Bambu A1 envelope without scaling QR or assembly fit
2026-10-09 Add standalone bevelled base preserving original plaque socket
2026-10-11 Add lighter elevated chick grate prototype with 0.2 mm module clearance
2026-10-11 Increase chick grate apertures to confirmed 8 mm in V2
2026-10-11 Add universal underside sockets, PETG clips and fit samples for chick grates
2026-10-12 Add validated A1 PLA 3MF project with 13 plates and standard clips
2026-10-12 Organize A1 PLA project into grid and standard clip plates
2026-10-13 Redraw Joana topper broom and close backing holes in V2
2026-10-15 Add Universo do Saber stand concept with assembly and color plan
2026-10-15 Add printable Universo do Saber phone stand
2026-10-15 Reinforce Universo base with charging window and front crossbar
2026-10-16 Preview 7mm Universo backrest with square support-free foot edges
2026-10-16 Build Universo do Saber V6 with 7mm backrest and support-free base
2026-10-17 Build printable M7 house and Christmas brick prototypes
2026-10-17 Sketch SR-71 Blackbird at 1:144 scale for A1 bed
2026-10-17 Use original STL seven for M7 brick V4 and verify printable project
2026-10-17 Add detailed SR-71A printable draft with validated A1 0.12 mm project
2026-10-18 Document measured M7 brick print-speed and four-body batch comparisons
2026-10-18 Add dimensioned three-part scout woggle proposal with five colors across two plates
2026-10-18 Illustrate independent sign-panel joints and rib termination with recovered QR destinations
2026-10-18 Build 220 mm clinic QR display with independent slots and ribbed backing
2026-10-19 Add wave-height base to 220 mm clinic display and dimensioned color visuals
2026-10-19 Update M7 house with original logo and deeper glue locating pockets
2026-10-20 Add hollow M size nest egg with validated A1 print profile
2026-10-22 Add 50 mm Bruna owl scout woggle with four color relief and A1 projects
2026-10-22 Sculpt curved Bruna owl relief and add validated A1 0.2 mm nozzle project
2026-10-23 Make standalone green owl scarf with top-only brown knot for 0.2 nozzle
2026-10-23 Restore original scarf fold panels and layered knot in two colors
2026-10-26 Add reinforced all-printed bearing puller prototype and staged PETG print project
2026-10-30 Make compact olive clinic display with organic flat base and lower material use
2026-10-30 Prepare final olive clinic base inverted with matching sample plate
2026-10-31 Restore 2 mm blue backing on the aligned M7 house
2026-11-01 Finish M7 white surface continuously before printing blue lettering
2026-11-03 Increase M7 plaque clearance to 0.30 mm per side
2026-11-04 Add orange-only plaque diagnostic print with V7 settings
2026-11-05 Add calibrated orange plaque corner path diagnostic V2
2026-11-05 Add scout wolf woggle with owl-sized oval bore and keyed glue-on face
2026-11-05 Review M7 plaque boundary, extrusion and fit hypotheses before further trials
2026-11-05 Preview wolf woggle with integrated gray body and glued color details
2026-11-06 Add approved four-speed gold calibration plate
2026-11-06 Record persistent gold junction defects across speed calibration
2026-11-06 Record persistent gold junction defects across wall-count samples
2026-11-06 Adapt calibrated gold line-fill strategy to Essencial base and sample
2026-11-07 Build connected Gallardo TOMAS illusion and validate A1 0.2 print project
2026-11-07 Add reusable calibrated orange user filament preset and orange Gallardo project
2026-11-08 Save ironing reference and channel review notes for future print projects
2026-11-08 Record overhang cooling tip and compare it with calibrated orange settings
2026-11-08 Revise chick drinker concept for inverted 500 ml bottle and printed-only mechanism
2026-11-08 Plan chick waterer with bottle rings and screw-on basin
2026-11-10 Add F1 Speed Champions wall support prototype
2026-11-10 Add wheel-integrated pilot shelf V9 concept
2026-11-10 Add reinforced print profile for F1 wall support
2026-11-10 Fix F1 support screw countersinks
2026-11-10 Add lithophane LED enclosure concept
2026-11-11 Add reusable calibrated gold filament preset
2026-11-11 Add 1.28 mm gold finish test for Essencial base
2026-11-12 Add offline wreath generator with dynamic text and glue supports
2026-11-12 Draft modular filament rack with four-way corner sockets
2026-11-13 Confirm 51 mm chick waterer bottle waist
2026-11-13 Detail printed-thread chick waterer cup concept
2026-11-13 Record chick waterer neck thread height
2026-11-13 Add provisional bottle thread fit coupons for chick waterer
2026-11-13 Store bottle thread test STL meshes in compact binary form
2026-11-13 Atualiza conceito da caixa litofania com placa LED real
2026-11-13 Regista leitura minima da placa LED e grampos ajustaveis
2026-11-13 Add recessed glued rear lid to lithophane box concept
2026-11-13 Add parametric lithophane LED box prototype
2026-11-13 Update lithophane LED box with measured board and USB port
2026-11-13 Confirm full LED board thickness for lithophane box
2026-11-13 Remove side opening from lithophane LED box
2026-11-13 Publish existing panda scarf ring CAD preview
2026-11-13 Show panda scarf ring with corrected arm pose
2026-11-13 Tilt panda head toward cheek paw in CAD preview
2026-11-13 Add diagnostic loose bottle thread fit test
